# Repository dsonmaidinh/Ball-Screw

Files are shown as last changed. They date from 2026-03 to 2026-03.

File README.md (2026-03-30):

# Dự án BallScrew Control

Tài liệu trong thư mục này giới thiệu hệ thống điều khiển BallScrew gồm phần cứng, phần mềm và firmware.

## Nội dung chính

- `App.png`: giao diện điều khiển và đồ thị hiển thị dữ liệu thời gian thực.
- `BallScrew.gif`: mô phỏng hoặc demo hoạt động cơ khí/điều khiển trong hệ thống.

## Mục tiêu

Dự án hướng tới xây dựng một hệ thống điều khiển vị trí/velocity cho cơ cấu BallScrew:

- STM32 F4 làm bộ điều khiển chính.
- Điều khiển PID kết hợp với encoder để theo dõi vị trí.
- Giao tiếp UART với phần mềm PC để hiển thị đồ thị và gửi lệnh.

## Hình ảnh minh họa

### Giao diện ứng dụng

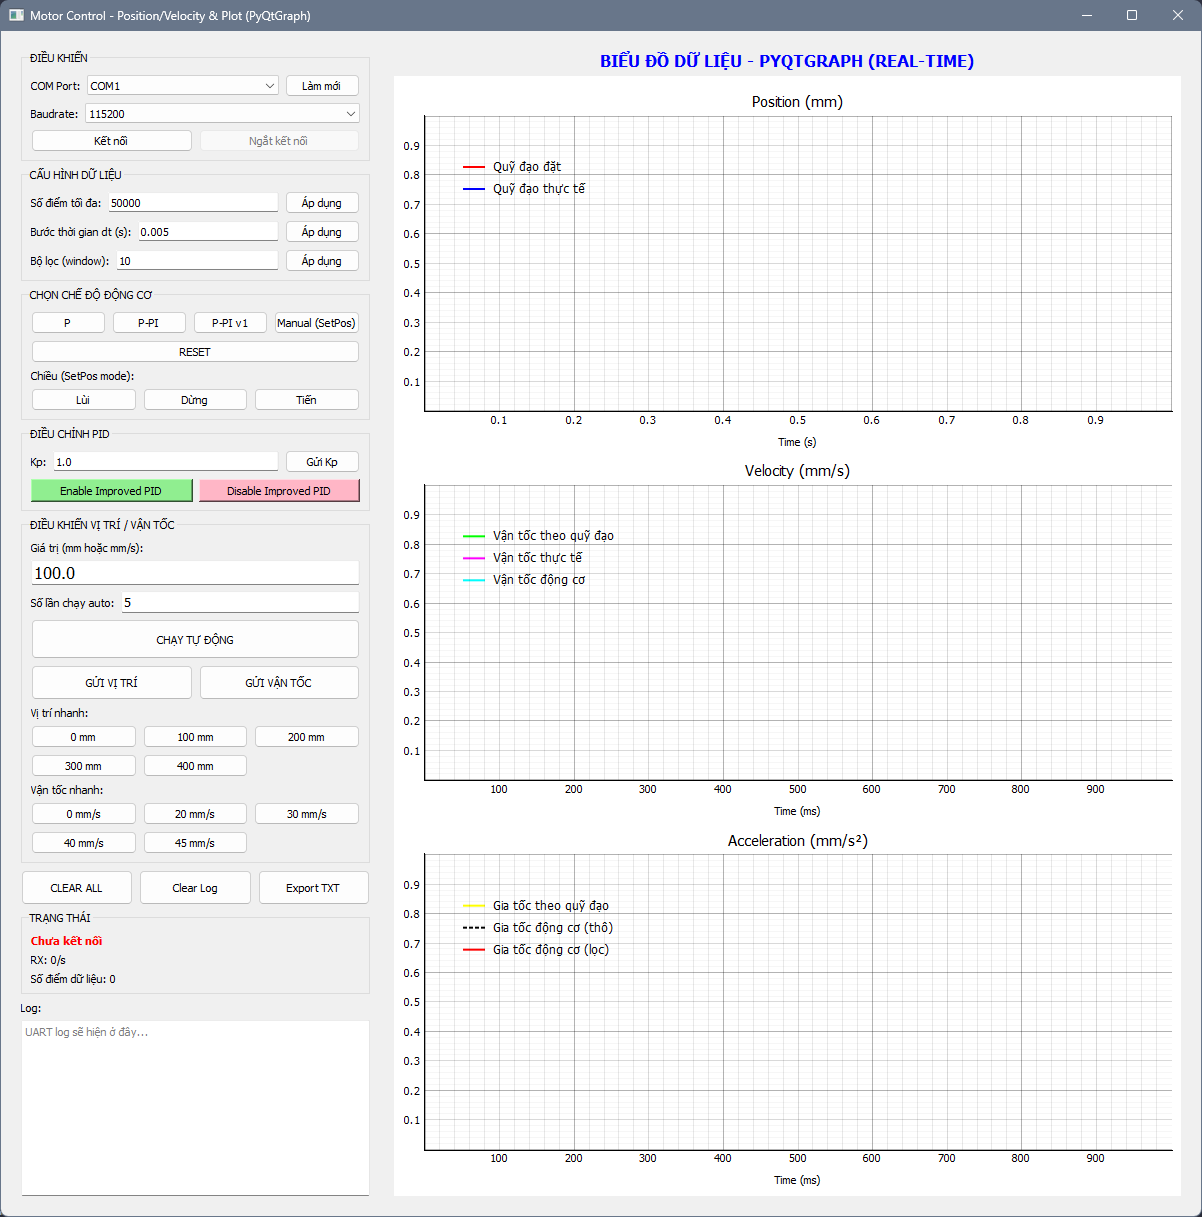
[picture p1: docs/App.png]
Giao diện ứng dụng điều khiển BallScrew


### Demo hoạt động

Demo hoạt động BallScrew

## Hướng dẫn nhanh

1. Mở firmware trong thư mục `firmware`.
2. Build và nạp vào STM32 F4.
3. Chạy ứng dụng PC trong `software/BallScrew.py`.
4. Kết nối cổng COM và bắt đầu điều khiển.

## Ghi chú

- Ảnh và GIF trong thư mục `docs` dùng để mô tả giao diện và trạng thái hệ thống.
- Tài liệu chính vẫn nằm trong README của từng phần `firmware`, `hardware`, `software`.

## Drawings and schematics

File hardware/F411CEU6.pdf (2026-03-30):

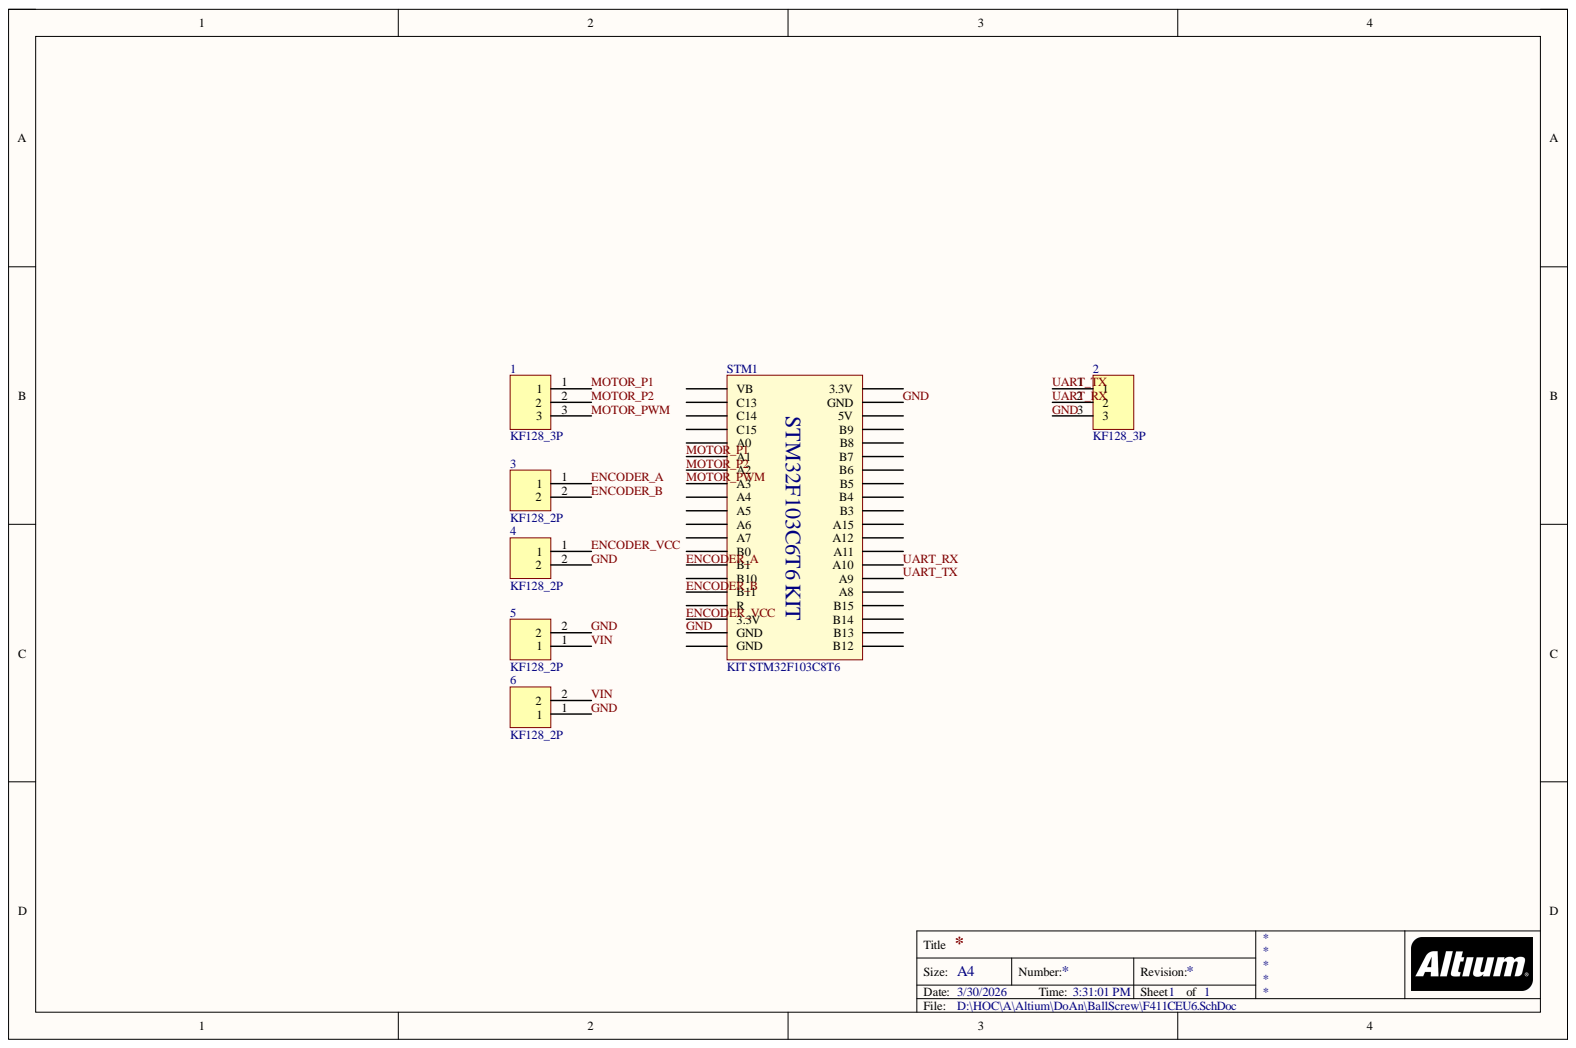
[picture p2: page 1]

Titl e * | **** *

Siz e : A4 | Numbe r : * | R evision : *

Da te : 3/30/202 6 Time : 3:31:01 P M | | She e t 1 o f 1

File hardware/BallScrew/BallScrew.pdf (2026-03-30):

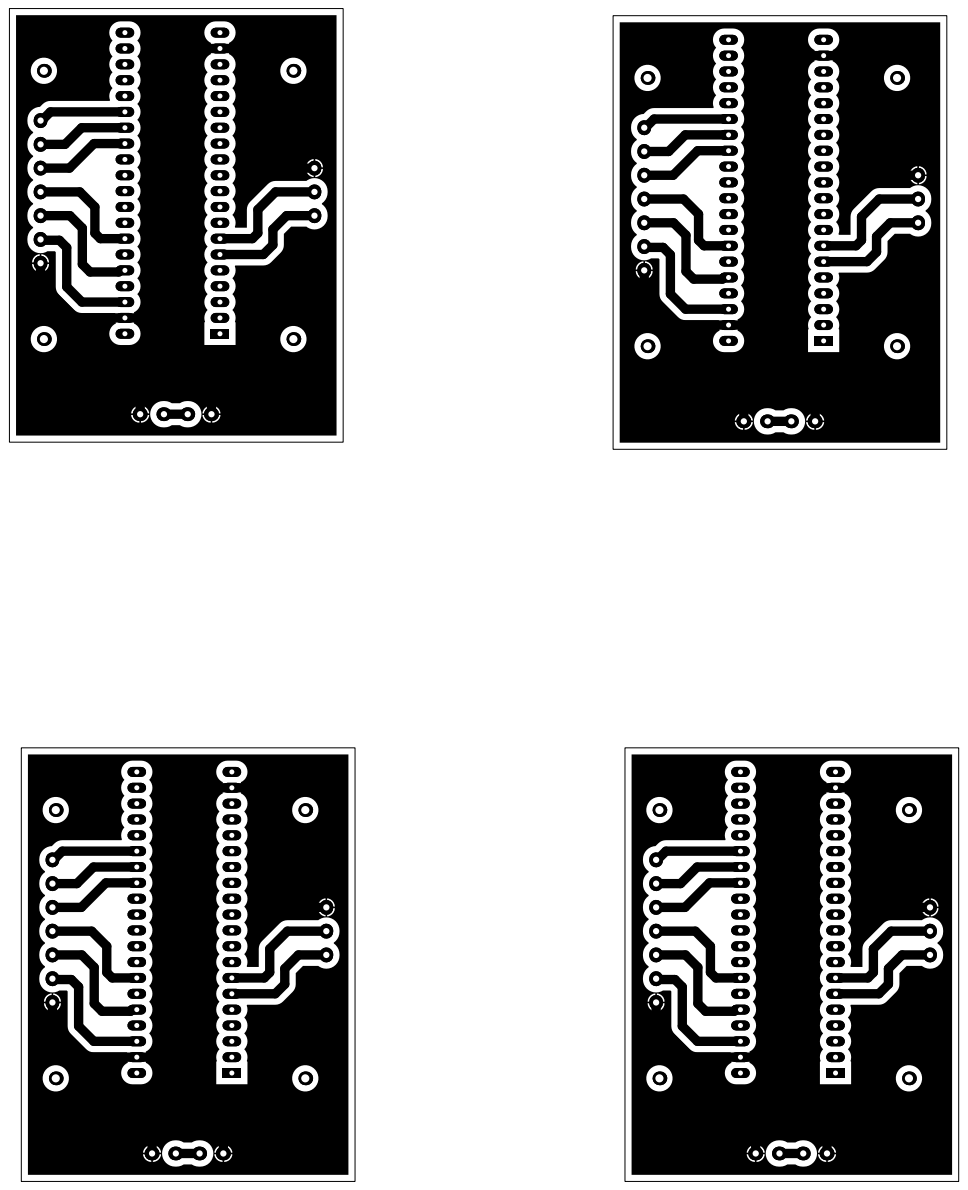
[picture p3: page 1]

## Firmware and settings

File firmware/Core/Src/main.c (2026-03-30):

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
/* Includes ------------------------------------------------------------------*/
#include "main.h"

/* USER CODE BEGIN Includes */
#include "stdio.h"
#include "string.h"
#include "stdlib.h"
#include "stdbool.h"
#include "math.h"

#include "encoder.h"
#include "motor.h"
#include "pid_controller.h"
#include "system_config.h"
#include "trajectory.h"
#include "uart.h"

/* USER CODE END Includes */

TIM_HandleTypeDef htim2;
TIM_HandleTypeDef htim4;

UART_HandleTypeDef huart1;
DMA_HandleTypeDef hdma_usart1_rx;
DMA_HandleTypeDef hdma_usart1_tx;

void SystemClock_Config(void);
static void MX_GPIO_Init(void);
static void MX_DMA_Init(void);
static void MX_TIM2_Init(void);
static void MX_USART1_UART_Init(void);
static void MX_TIM4_Init(void);
/* USER CODE BEGIN PFP */
//=== Vel: PI
#if 1
float Kp 	= 8.7719;
float Ki 	= 438.5965;
float Kb 	= 50.0000;
float Kd  = 0;
float alpha_vel = 0.0f;

//float Kp 	= 23.3;
//float Ki 	= 776.67;
//float Kb 	= 33.33;//;
//float Kd  = 0;
//float alpha_vel = 0.0f;
#endif
#if 0
float Kp 	= 1.1363;//0.2058;
float Ki 	= 37.8261;//6.3327;
float Kb 	= 33.2889;//;
float Kd  = 0;
float alpha_vel = 0.0f;
#endif
//=== Improved Profile Gains
float	Kp_pos = 800.0;
float Kpp_improved = 10.0;   // P gain position controller
//float Kpp_improved = 5.0;   // P gain position controller
float Kest = 100000.0;           // Estimation gain (< 1.0: overdamped, > 1.0: underdamped)
float Kcom = 20.0;           	 // Compensation gain (< 1.0: overdamped, > 1.0: underdamped)
//=== Uart
char Rx_indx, Rx_Buffer[MaxBuffer],Rx_data[MaxBuffer];
//char Tx_Buffer[MaxBuffer];
volatile uint8_t uart1_flag = 0;

encoder Encoder = {0};
motor Motor = {0};
pid_controller PIDVel;
pid_controller PIDPos;
Trajectory_t trajectory = {0};
/* USER CODE END PFP */

/* USER CODE BEGIN 0 */
float max_pwm_P = SYS_MaxPWM_P;
float speed = 0;
int8_t chieu = 0;
uint32_t count_element = 0;
char Tx_Buffer[MaxBuffer];  // 2 buffer xen kẽ
volatile uint8_t active_buffer = 0;
volatile uint8_t dma_busy = 0;
PlotBuffer_t plot_buffer = {0};

void HAL_TIM_PeriodElapsedCallback(TIM_HandleTypeDef *htim) {
    if(htim->Instance == TIM4) {    // 5ms
			switch(Motor.mode){
				case MOTOR_SetPos:
					MOTOR_CalculateParams(&Motor, &Encoder, trajectory.sign, trajectory.phase);
					speed = Motor.CurVel_rad;
					if(chieu == -1) Motor.pwm = -1000;
					else if(chieu == 0) Motor.pwm = 0;
					else Motor.pwm = 1000;					break;
				
				case MOTOR_P_PI:
					// TÍNH TOÁN THÔNG SỐ
					MOTOR_CalculateParams(&Motor, &Encoder, trajectory.sign, trajectory.phase);
					// CẬP NHẬT TRAJECTORY
					if(trajectory.use_v1) TRAJ_DrawTrajectory_v1(&trajectory);
					else TRAJ_DrawTrajectory(&trajectory);
					// PID VỊ TRÍ
					Motor.DesiredVel_mm = PID_Pos_Improved(&PIDPos, trajectory.q_desired, Motor.CurPos_mm);
					Motor.DesiredVel_rad = Motor.DesiredVel_mm * SYS_MM2RAD;
					//if(fabs(Motor.DesiredVel_rad) < 0.85) Motor.DesiredVel_rad = 0;
					// PID VẬN TỐC
					Motor.pwm = PID_Vel(&PIDVel, Motor.DesiredVel_rad, Motor.CurVel_rad, trajectory.phase, trajectory.sign);
					break;
				case MOTOR_P:
					// TÍNH TOÁN THÔNG SỐ
					MOTOR_CalculateParams(&Motor, &Encoder, trajectory.sign, trajectory.phase);
					// CẬP NHẬT TRAJECTORY
					if(trajectory.use_v1) TRAJ_DrawTrajectory_v1(&trajectory);
					else TRAJ_DrawTrajectory(&trajectory);
					// PID VỊ TRÍ
					Motor.pwm = PID_Pos_Simple(&PIDPos, trajectory.q_desired, Motor.CurPos_mm);
					

					break;
			}
			if(Motor.tick_enabled) Motor.tick++;
			MOTOR_SetRun(&Motor);
			#if 1
			if (Motor.plot_active) {
            // Ghi d? li?u vào buffer
            if (plot_buffer.count < PLOT_BUFFER_SIZE) {
                PlotData_t *data = &plot_buffer.buffer[plot_buffer.write_idx];
                
                data->q_desired = trajectory.q_desired_prev;
                data->q_actual = Motor.CurPos_mm;
                data->v_desired = 0.0;
                data->v_actual = (float)Motor.DesiredVel_mm;
                data->v_motor = Motor.CurVel_mm;
                data->a_desired = 0.0;
                data->a_motor = Motor.Acc_mm;
								data->pwm = Motor.pwm;
								
                plot_buffer.write_idx = (plot_buffer.write_idx + 1) % PLOT_BUFFER_SIZE;
                
                // CRITICAL: Tang count ph?i atomic
                __disable_irq();
                plot_buffer.count++;
                __enable_irq();
            }
        }
			// Cập nhật state
			trajectory.v_desired_prev = trajectory.v_desired;
			trajectory.q_desired_prev = trajectory.q_desired;
			#endif
    }
}
void HAL_UART_TxCpltCallback(UART_HandleTypeDef *huart) {
    if(huart->Instance == USART1) {
        dma_busy = 0;  // Cho phép gửi tiếp
    }
}  
/* USER CODE END 0 */

/**
  * @brief  The application entry point.
  * @retval int
  */
int main(void)
{

  /* MCU Configuration--------------------------------------------------------*/

  /* Reset of all peripherals, Initializes the Flash interface and the Systick. */
  HAL_Init();

  /* Configure the system clock */
  SystemClock_Config();

  /* Initialize all configured peripherals */
  MX_GPIO_Init();
  MX_DMA_Init();
  MX_TIM2_Init();
  MX_USART1_UART_Init();
  MX_TIM4_Init();
  /* Infinite loop */
  /* USER CODE BEGIN WHILE */
	//--- Timer
	HAL_TIM_Base_Start_IT(&htim4);
	//--- PWM
	HAL_TIM_PWM_Start(&htim2, TIM_CHANNEL_3);
	//--- UART
	UART_Receive_Enable(&huart1, (uint8_t *)Rx_Buffer, MaxBuffer);
	//--- SetParams
	
	MOTOR_SetParams(&Motor, TIM_CHANNEL_3, MOTOR_PIN_1, MOTOR_PIN_2, MOTOR_SetPos, MOTOR_MAXVEL_MM);
	PID_SetParams(&PIDVel, Kp, Ki, Kd, Kb, alpha_vel, SYS_MaxPWM, SYS_SAMPLETIME);
	if(Motor.mode == MOTOR_P)PID_SetParamsImproved(&PIDPos, Kp_pos, SYS_MaxPWM_P, SYS_SAMPLETIME, Kest, Kcom, Motor.a_max_mm);
	else PID_SetParamsImproved(&PIDPos, Kpp_improved, Motor.v_max_mm, SYS_SAMPLETIME, Kest, Kcom, Motor.a_max_mm);
	PID_ResetState(&PIDPos);

	TRAJ_SetParams(&trajectory, SYS_SAMPLETIME, SYS_RUN_TIME, SYS_STOP_TIME, Motor.a_max_mm * 2.0, Motor.v_max_mm);
	
	float Kpp_improved_pre = Kpp_improved;
	float preKest = Kest;
	float preKcom = Kcom;
	float premax_pwm_P = max_pwm_P;
	float preKp_pos = Kp_pos;
//	trajectory.test = 1;
//	Motor.pwm = 1000;
//	trajectory.sign = 1;
//	HAL_Delay(1000);
//	MOTOR_SetRun(&Motor);
//	__HAL_TIM_SetCompare(&htim2, TIM_CHANNEL_3, 1000);
  while (1)
  {
			#if 1
			if(plot_buffer.reset) {
					chieu = 0;
					memset(Tx_Buffer, 0, sizeof(Tx_Buffer));
					UART_ResetPlotData(&plot_buffer);
				
					MOTOR_ResetParams(&Motor);
					ENCODER_ResetParams(&Encoder);
					TRAJ_ResetParams(&trajectory);
					PID_ResetParams(&PIDVel);
					plot_buffer.reset = 0;
					HAL_Delay(200);
			}
			switch(Motor.mode){
					case MOTOR_SetPos:
						break;
					
					case MOTOR_P_PI:
							if (plot_buffer.count > 0 && !dma_busy) {
									PlotData_t *data = &plot_buffer.buffer[plot_buffer.read_idx];
									
									int len = snprintf(Tx_Buffer, MaxBuffer,
																		"%.3f %.3f %.3f %.3f %.3f %.3f %.3f %.3f 0.0\r\n",
																		data->q_desired,
																		data->q_actual,
																		data->v_desired,
																		data->v_actual,
																		data->v_motor,
																		data->a_desired,
																		data->a_motor,
																		data->pwm
																		);
									
									if (len > 0 && len < MaxBuffer) {
											dma_busy = 1;
											HAL_UART_Transmit_DMA(&huart1, (uint8_t *)Tx_Buffer, len);
											
											plot_buffer.read_idx = (plot_buffer.read_idx + 1) % PLOT_BUFFER_SIZE;
											
											__disable_irq();
											plot_buffer.count--;
											__enable_irq();
											
											count_element++;
									}
							}
						if(trajectory.phase == TRAJ_PHASE_STOP) {  // Đã gần đích
								Motor.tick_enabled = 1;
								
								if(Motor.tick >= 400){  // 400 * 5ms = 2s
										// Sau 2s mà vẫn sai số > 10mm => CÓ LỖI
										if(fabs(trajectory.q_desired - Motor.CurPos_mm) > 10.0) {
												plot_buffer.reset = 1;
												PIDVel.err_state = 1;
										}
										else {
												// Đã ổn định => tắt tick
												Motor.check = 0;
												Motor.tick_enabled = 0;
										}
										Motor.tick = 0;
								}
						}
						else {
								// Động cơ đang chuyển động hoặc chưa gần đích => KHÔNG kiểm tra lỗi
								Motor.tick_enabled = 0;
								Motor.tick = 0;
						}
						break;
					case MOTOR_P:
							if (plot_buffer.count > 0 && !dma_busy) {
								PlotData_t *data = &plot_buffer.buffer[plot_buffer.read_idx];
								
								int len = snprintf(Tx_Buffer, MaxBuffer,
																	"%.3f %.3f %.3f %.3f %.3f %.3f %.3f %.3f 0.0\r\n",
																	data->q_desired,
																	data->q_actual,
																	0.0,
																	0.0,
																	data->v_motor,
																	0.0,
																	data->a_motor,
																	data->pwm
																	);
								
								if (len > 0 && len < MaxBuffer) {
										dma_busy = 1;
										HAL_UART_Transmit_DMA(&huart1, (uint8_t *)Tx_Buffer, len);
										
										plot_buffer.read_idx = (plot_buffer.read_idx + 1) % PLOT_BUFFER_SIZE;
										
										__disable_irq();
										plot_buffer.count--;
										__enable_irq();
										
										chieu += 1.0;
								}
						}
						break;
				}
				if(Motor.DesiredPos_mm != Motor.DesiredPos_mm_pre){
						trajectory.plot_active = 1;
						trajectory.move_active = 1;
						Motor.plot_active = 1;
						Motor.tick_enabled = 0;
						Motor.tick = 0;
						Motor.DesiredPos_mm_pre = Motor.DesiredPos_mm;
								TRAJ_SetupMultiSegmentMove_100mm(&trajectory, Motor.DesiredPos_mm);
								TRAJ_ContinueNextSegment_100mm(&trajectory);
						PID_ResetState(&PIDPos);
				}
				if(trajectory.phase == TRAJ_PHASE_COMPLETE && 
					 (fabs(Motor.DesiredPos_mm - Motor.CurPos_mm)) <= Motor.cycle_error[Motor.cycle_index] && 
					 Motor.auto_run)
				{
						if(Motor.cycle_count > 0){
								// Kiểm tra đang ở vị trí nào
								if(fabs(Motor.DesiredPos_mm_pre) < 0.1){
										// Đang ở vị trí 0 → Đi đến vị trí đích
										Motor.DesiredPos_mm = Motor.AutoDesiredPos_mm;
								} else {
										// Đang ở vị trí đích → Quay về 0
										Motor.DesiredPos_mm = 0;
										
										// Giảm cycle sau khi hoàn thành 1 chu kỳ đầy đủ (đi + về)
										Motor.cycle_count--;
								}
						}
						else {
								// Hết cycle → Dừng auto_run
								Motor.auto_run = 0;
								Motor.DesiredPos_mm_pre = 0;
						}
				}
				#endif
				HAL_Delay(1);
    /* USER CODE END WHILE */

    /* USER CODE BEGIN 3 */
  }
  /* USER CODE END 3 */
}

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
/* USER CODE BEGIN 4 */
struct __FILE
{
  int handle;
  
};
/* FILE is typedef'd in stdio.h. */
FILE __stdout;
int fputc(int ch, FILE *f)
{
  /* Your implementation of fputc(). */
	HAL_UART_Transmit(&huart1, (uint8_t *) &ch,1,100);
//	HAL_UART_Transmit_DMA(&huart1, (uint8_t *) &ch,1);

  return ch;
}
// Ham ngat Uart
void HAL_UARTEx_RxEventCallback(UART_HandleTypeDef *huart, uint16_t Size){
    if (huart->Instance == USART1)
    {
        UART_Receive_Enable(&huart1, (uint8_t *)Rx_Buffer, MaxBuffer);
        
				char first_char = Rx_Buffer[0];
				if(first_char == 'r'){
						plot_buffer.reset = 1;
						PIDVel.err_state = 0;
						return;
				}
				memcpy(Rx_data, Rx_Buffer, MaxBuffer * sizeof(Rx_Buffer[0]));
				switch(first_char){
					case 'm':
								MOTOR_ResetParams(&Motor);
								ENCODER_ResetParams(&Encoder);
								TRAJ_ResetParams(&trajectory);
								if(strcmp(Rx_Buffer, "mode 0") == 0){
										Motor.cycle_index = 1;
										MOTOR_UpdateMode(&Motor, MOTOR_P);
										PID_SetParamsImproved(&PIDPos, Kp_pos, SYS_MaxPWM_P, SYS_SAMPLETIME, Kest, Kcom, Motor.a_max_mm);
								}
								else if(strcmp(Rx_Buffer, "mode 1") == 0){
										Kpp_improved = 5.0;
										trajectory.use_v1 = 0;
										Motor.cycle_index = 0;
										MOTOR_UpdateMode(&Motor, MOTOR_P_PI);
										PID_SetParamsImproved(&PIDPos, Kpp_improved, Motor.v_max_mm, SYS_SAMPLETIME, Kest, Kcom, Motor.a_max_mm);
								}
								else if(strcmp(Rx_Buffer, "mode 2") == 0){
										trajectory.use_v1 = 1;
										Motor.cycle_index = 0;
										MOTOR_UpdateMode(&Motor, MOTOR_P_PI);
										PID_SetParamsImproved(&PIDPos, Kpp_improved, Motor.v_max_mm, SYS_SAMPLETIME, Kest, Kcom, Motor.a_max_mm);
								}
								else{
										MOTOR_UpdateMode(&Motor, MOTOR_SetPos);
										trajectory.sign = 1;
								}
								plot_buffer.reset = 1;
								break;
					case 'c':
								if(Motor.mode == MOTOR_SetPos){
										if(strcmp(Rx_Buffer, "c-1") == 0){
												chieu = -1;
										}
										else if(strcmp(Rx_Buffer, "c0") == 0){
												chieu = 0;
										}
										else{
												chieu = 1;
										}
								}
					case 'x':
										{
											char *token1 = strtok(Rx_Buffer + 1, "x");  // Bỏ ký tự 'x' đầu
											char *token2 = strtok(NULL, "x");
											
											if (token1 != NULL && token2 != NULL) {
													int position = atof(token1);
													int cycles = atoi(token2);
													
													// Lưu vào struct trajectory hoặc motor
													MOTOR_UpdatePos(&Motor, position);
													Motor.AutoDesiredPos_mm = Motor.DesiredPos_mm;
													Motor.cycle_count = cycles;
													Motor.auto_run = 1;  // Bật chế độ chu trình
											}
										}
										break;
					default:
								break;
				}
				
				if(Motor.mode != MOTOR_SetPos){
						// Lấy ký tự cuối cùng làm command
						char last_char = Rx_Buffer[Size - 1];
						
						switch(last_char) {
								case 's':
										// Thay ký tự 's' bằng null terminator để atoi chỉ đọc phần số
										Rx_Buffer[Size - 1] = '\0';
										MOTOR_UpdatePos(&Motor, atoi(Rx_Buffer));
										break;
										
								case 'v':
										if(Motor.mode == MOTOR_P) break;
										// Thay ký tự 'v' bằng null terminator để atoi chỉ đọc phần số
										Rx_Buffer[Size - 1] = '\0';
										MOTOR_UpdateVel(&Motor, atoi(Rx_Buffer));
										
										PID_SetParamsImproved(&PIDPos, Kpp_improved, Motor.v_max_mm, SYS_SAMPLETIME, Kest, Kcom, Motor.a_max_mm);
										TRAJ_SetParams(&trajectory, SYS_SAMPLETIME, SYS_RUN_TIME, SYS_STOP_TIME, Motor.a_max_mm, Motor.v_max_mm);
										break;    
										
								case 'p':
										Rx_Buffer[Size - 1] = '\0';
										if(Motor.mode == MOTOR_P){
												Kp_pos = atof(Rx_Buffer);
												PID_SetParamsImproved(&PIDPos, Kp_pos, SYS_MaxPWM_P, SYS_SAMPLETIME, Kest, Kcom, Motor.a_max_mm);
										}
										else{
												Kpp_improved = atof(Rx_Buffer);
												PID_SetParamsImproved(&PIDPos, Kpp_improved, Motor.v_max_mm, SYS_SAMPLETIME, Kest, Kcom, Motor.a_max_mm);
										}
								case 'e':
										if(Motor.mode == MOTOR_P) break;
										Rx_Buffer[Size - 1] = '\0';
										if(atoi(Rx_Buffer) == 0)	PID_DisableImproved(&PIDPos);
										else PID_EnableImproved(&PIDPos);
										break;

								default:
										break;
						}
				}
        
        // Reset buffer
        memset(Rx_Buffer, 0, sizeof(Rx_Buffer));
    }
}

void HAL_GPIO_EXTI_Callback(uint16_t GPIO_Pin){
    if(GPIO_Pin == Encoder_A || GPIO_Pin == Encoder_B) {
        ProcessEncoder(&Encoder, Encoder_A, Encoder_B);
    }
}
/* USER CODE END 4 */
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


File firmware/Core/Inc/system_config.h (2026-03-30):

#ifndef SYSTEM_CONFIG_H
#define SYSTEM_CONFIG_H

#include <stdint.h>
//#include "motor.h"

// TOÁN HỌC
#define SYS_PI 							3.1415
#define SYS_RAD2MM					2.0/SYS_PI
#define SYS_MM2RAD					SYS_PI/2.0
// HỆ VÍT ME
#define SYS_PB							4.0
#define SYS_MAXLENGTH				400.0
#define SYS_MINLENGTH				0.0
// ĐỘNG CƠ
#define MOTOR_PORT 			GPIOA
#define MOTOR_PIN_1			0
#define MOTOR_PIN_2			1
#define SYS_SAMPLETIME			0.005
// ENCODER
#define Encoder_Port		GPIOB
#define Encoder_A				GPIO_PIN_0
#define Encoder_B				GPIO_PIN_2
#define Encoder_ppr 		8000

#define SYS_MaxPWM				  1000
#define SYS_MaxPWM_P			  800
// THỜI GIAN
#define SYS_RUN_TIME				2.1
#define SYS_STOP_TIME				12.9
#endif

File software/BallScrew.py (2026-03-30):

import sys
import threading
import time
from collections import deque

from PyQt5 import QtCore, QtGui, QtWidgets
import serial
import serial.tools.list_ports

import pyqtgraph as pg
from pyqtgraph import PlotWidget, PlotItem


# ---------------------------
# PyQtGraph Canvas Widget
# ---------------------------
class PyQtGraphCanvas(pg.GraphicsLayoutWidget):
    def __init__(self, parent=None):
        super().__init__(parent)
        
        # Set background
        self.setBackground('w')
        
        # Create subplots
        self.pos_plot = self.addPlot(title="Position (mm)", row=0, col=0)
        self.nextRow()
        self.vel_plot = self.addPlot(title="Velocity (mm/s)", row=1, col=0)
        self.nextRow()
        self.acc_plot = self.addPlot(title="Acceleration (mm/s²)", row=2, col=0)
        
        # Link X axes
        self.vel_plot.setXLink(self.pos_plot)
        self.acc_plot.setXLink(self.pos_plot)
        
        # Configure plots
        for plot in [self.pos_plot, self.vel_plot, self.acc_plot]:
            plot.showGrid(x=True, y=True, alpha=0.3)
            plot.addLegend()
        
        # Data curves
        self.curves = {}
        self._setup_curves()
    
    def _setup_curves(self):
        # Position curves
        self.curves['dpos'] = self.pos_plot.plot(pen=pg.mkPen('r', width=2), name="Quỹ đạo đặt")
        self.curves['cpos'] = self.pos_plot.plot(pen=pg.mkPen('b', width=2), name="Quỹ đạo thực tế")
        
        # Velocity curves  
        self.curves['vdes'] = self.vel_plot.plot(pen=pg.mkPen('g', width=2), name="Vận tốc theo quỹ đạo")
        self.curves['vactual'] = self.vel_plot.plot(pen=pg.mkPen('m', width=2), name="Vận tốc thực tế")
        self.curves['vmotor'] = self.vel_plot.plot(pen=pg.mkPen('c', width=2), name="Vận tốc động cơ")
        
        # Acceleration curves
        self.curves['ades'] = self.acc_plot.plot(pen=pg.mkPen('y', width=2), name="Gia tốc theo quỹ đạo")
        self.curves['amotor'] = self.acc_plot.plot(pen=pg.mkPen('k', width=2, style=QtCore.Qt.DotLine), name="Gia tốc động cơ (thô)")
        self.curves['amotor_filtered'] = self.acc_plot.plot(pen=pg.mkPen('r', width=2), name="Gia tốc động cơ (lọc)")
        
        # Set X-axis label to time
        self.pos_plot.setLabel('bottom', 'Time', units='s')
        self.vel_plot.setLabel('bottom', 'Time', units='s')
        self.acc_plot.setLabel('bottom', 'Time', units='s')
    
    def update_plot(self, x, pos_data, vel_data, acc_data):
        # Update all curves with new data
        self.curves['dpos'].setData(x, pos_data[0])
        self.curves['cpos'].setData(x, pos_data[1])
        
        self.curves['vdes'].setData(x, vel_data[0])
        self.curves['vactual'].setData(x, vel_data[1])
        self.curves['vmotor'].setData(x, vel_data[2])
        
        self.curves['ades'].setData(x, acc_data[0])
        self.curves['amotor'].setData(x, acc_data[1])
        self.curves['amotor_filtered'].setData(x, acc_data[2])
    
    def clear_plot(self):
        # Clear all curve data
        for curve in self.curves.values():
            curve.clear()
        
        # Reset plot ranges
        for plot in [self.pos_plot, self.vel_plot, self.acc_plot]:
            plot.enableAutoRange()


# ---------------------------
# Serial Reader Thread
# ---------------------------
class SerialReader(QtCore.QObject):
    line_received = QtCore.pyqtSignal(str)
    connected = QtCore.pyqtSignal(bool)

    def __init__(self):
        super().__init__()
        self.ser = None
        self._running = False
        self._thread = None

    def list_ports(self):
        return [p.device for p in serial.tools.list_ports.comports()]

    def open(self, port, baud):
        try:
            self.ser = serial.Serial(port=port, baudrate=baud, timeout=0.01)
            self._running = True
            self._thread = threading.Thread(target=self._reader_loop, daemon=True)
            self._thread.start()
            self.connected.emit(True)
            return True
        except Exception as e:
            self.connected.emit(False)
            QtWidgets.QMessageBox.critical(None, "Serial Error", str(e))
            return False

    def _reader_loop(self):
        buf = bytearray()
        while self._running and self.ser is not None:
            try:
                data = self.ser.read(512)
                if data:
                    buf.extend(data)
                    while b'\n' in buf:
                        line, _, buf = buf.partition(b'\n')
                        try:
                            s = line.decode('utf-8', errors='ignore').strip()
                            if s:
                                self.line_received.emit(s)
                        except Exception:
                            pass
                else:
                    time.sleep(0.001)
            except Exception:
                break
        self.connected.emit(False)

    def write_text(self, text: str):
        if self.ser and self.ser.is_open:
            try:
                self.ser.write(text.encode('utf-8'))
            except Exception as e:
                QtWidgets.QMessageBox.warning(None, "Write Error", str(e))

    def close(self):
        self._running = False
        try:
            if self.ser:
                self.ser.close()
        except Exception:
            pass
        self.ser = None
        self.connected.emit(False)
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

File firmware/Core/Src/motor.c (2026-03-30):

#include "motor.h"
#include "stm32f4xx.h"
#include "system_config.h"
#include <stdbool.h>
#include <math.h>

extern TIM_HandleTypeDef htim2;

void MOTOR_SetRun(motor *Motor){
		int8_t next_dir = 0;
    
    // 1. Xác định hướng TƯƠNG LAI dựa trên PWM
    if(Motor->pwm >= 0) {
        next_dir = 1; // Ví dụ: -1 là chiều thuận
    } else {
        next_dir = -1;  // Ví dụ: 1 là chiều nghịch
    }

    // 2. So sánh hướng tương lai và hướng hiện tại
    if(next_dir != Motor->dir){
        // Nếu đảo chiều, Reset cả 2 chân trước để tránh xung đột
        MOTOR_PORT->ODR &= ~((1<<Motor->mpin[0]) | (1<<Motor->mpin[1]));
        Motor->dir = next_dir; // Cập nhật hướng mới
    }
    
    // 3. Thực hiện điều khiển
    Motor->pwm_real = (Motor->pwm >= 0) ? Motor->pwm : -Motor->pwm;
    static int8_t pre_dir = 0;
    if(Motor->pwm >= 0) {
        MOTOR_PORT->ODR |= 1<<Motor->mpin[0];
    }
    else if(Motor->pwm < 0) {
        MOTOR_PORT->ODR |= 1<<Motor->mpin[1];
    }
    __HAL_TIM_SetCompare(&htim2, Motor->pwmchannel, Motor->pwm_real);
}

void MOTOR_SetParams(motor *Motor, uint32_t ch, uint8_t pin1, uint8_t pin2, MotorMode mode, float max_speed_mm){
    Motor->pwmchannel = ch;
    Motor->mpin[0]    = pin1;
    Motor->mpin[1]    = pin2;
    
		Motor->cycle_error[0] = 0.1;
		Motor->cycle_error[1] = 0.9;
	
    Motor->state      = MOTOR_IDLE;
    Motor->prev_state = MOTOR_IDLE;
	
		Motor->v_max_mm	  =	max_speed_mm;
		Motor->a_max_mm	  = (max_speed_mm/MOTOR_RESPONSETIME)*MOTOR_MAXACC_SF;
		MOTOR_UpdateMode(Motor, mode);
}

void MOTOR_ResetParams(motor *Motor){
		Motor->DesiredPos_mm = 0;
		Motor->DesiredPos_mm_pre = 0;
		Motor->CurPos_mm = 0;
	
		Motor->DesiredVel_mm = 0;
		Motor->DesiredVel_rad = 0;
	
		Motor->plot_active = 0;
		Motor->auto_run = 0;
		Motor->cycle_count = 0;
		//Motor->cycle_index = 0;
		Motor->tick = 0;
		Motor->tick_enabled = 0;
		Motor->check = 0;
		MOTOR_PORT->ODR &= ~((1<<Motor->mpin[0]) | (1<<Motor->mpin[1]));
}

void MOTOR_UpdateMode(motor *Motor, MotorMode mode){
		Motor->mode       = mode;
		if(mode == MOTOR_P) Motor->err_pos = 0.5;
		else Motor->err_pos = 0.01;
}
void MOTOR_UpdateVel(motor *Motor, float vel){
		Motor->v_max_mm	  =	vel;
		if (Motor->v_max_mm >= MOTOR_MAXVEL_MM) Motor->v_max_mm = MOTOR_MAXVEL_MM;
    if (Motor->v_max_mm <= MOTOR_MINVEL_MM) Motor->v_max_mm = MOTOR_MINVEL_MM;
		Motor->a_max_mm	  = (Motor->v_max_mm/MOTOR_RESPONSETIME)*MOTOR_MAXACC_SF;
}
void MOTOR_UpdatePos(motor *Motor, float pos){
		Motor->DesiredPos_mm	  =	pos;
		if (Motor->DesiredPos_mm >= SYS_MAXLENGTH) Motor->DesiredPos_mm = SYS_MAXLENGTH;
    if (Motor->DesiredPos_mm <= SYS_MINLENGTH) Motor->DesiredPos_mm = SYS_MINLENGTH;
}

void MOTOR_CalculateParams(motor *Motor, encoder *Encoder, float sign, MotionPhase_t phase){
    Encoder->Cnttmp 	= Encoder->CntVel;
    Encoder->CntVel 	= 0;
    Motor->CurVel_rad = sign * Encoder->Cnttmp * MOTOR_VEL_CONVERSION_FACTOR_RAD;
    Motor->CurPos_mm 	= ((float)Encoder->PosCnt + (float)Encoder->CountValue / (float)Encoder_ppr) * SYS_PB;
    
    // Chuyển đổi vận tốc sang mm/s để so sánh
    if(Motor->mode == MOTOR_P) Motor->CurVel_mm = Motor->CurVel_rad;
    else Motor->CurVel_mm = Motor->CurVel_rad * SYS_RAD2MM;
    
    // Lọc nhiễu: nếu vận tốc thực tế < ngưỡng nhiễu thì coi như 0
    if(fabs(Motor->CurVel_mm) < MOTOR_DEADZONE_VEL) {
        Motor->CurVel_mm = 0.0f;
    }
//else Motor->state = MOTOR_ACCEL;
    
    Motor->vel_diff = Motor->CurVel_mm - Motor->CurVel_mm_pre;

    //MOTOR_CalculateTime_v1(Motor, time, phase);
    if(fabs(Motor->DesiredPos_mm - Motor->CurPos_mm) < Motor->err_pos && phase == TRAJ_PHASE_COMPLETE){
        Motor->plot_active = 0;
    }
		
    Motor->CurVel_mm_pre = Motor->CurVel_mm;
    
    // Tính gia tốc thực tế
    Motor->Acc_mm = 0.8f * Motor->Acc_mm + 0.2f * ((Motor->vel_diff) / SYS_SAMPLETIME);
}

// void MOTOR_CalculateTime(motor *Motor) {
//     static float t_stable_count = 0.0f;    // Thời gian ổn định
//     static float prev_pos = 0.0f;          // Vị trí trước để để kiểm tra
//     static bool is_stabilizing = false;    // Đang trong quá trình ổn định
    
//     float error_at_max_speed = fabs(Motor->v_max_mm - Motor->CurVel_mm);
    
//     // ========== GIAI ĐOẠN ỔN ĐỊNH (sau khi giảm tốc) ==========
//     // Phát hiện bắt đầu ổn định: DesiredSpeed về 0 Và CurVel gần 0
//     if(fabs(Motor->DesiredVel_mm) < MOTOR_ACCEL_START_THRESHOLD && 
//        fabs(Motor->CurVel_mm) < MOTOR_DEADZONE_VEL && 
//        Motor->state == MOTOR_DECEL && 
//        !is_stabilizing) {
//         is_stabilizing = true;
//         t_stable_count = 0.0f;
//         prev_pos = Motor->CurPos_mm;
//         Motor->state = MOTOR_IDLE;
//     }
//     if(fabs(Motor->DesiredPos_mm - Motor->CurPos_mm) < 0.01f){
//         is_stabilizing = false;
//         t_stable_count = 0.0f;
//         Motor->t_motor_adjust = 0.0f;
//         Motor->state = MOTOR_IDLE;
//         Motor->plot_active = 0;
//     }
//     // Đang trong giai đoạn ổn định
//     if(is_stabilizing) {
//         float pos_change = fabs(Motor->CurPos_mm - prev_pos);
        
//         // Nếu vị trí thay đổi -> reset bộ đếm (động cơ vẫn đang điều chỉnh)
//         if(pos_change > 0.001f)  {
//             t_stable_count = 0.0f;
//             prev_pos = Motor->CurPos_mm;
//             Motor->t_motor_adjust += SYS_SAMPLETIME;  // Tích lũy thời gian tự điều chỉnh
//         }
//         else {
//             // Vị trí không đổi -> tăng bộ đếm
//             t_stable_count += SYS_SAMPLETIME;
//         }
        
//         // Nếu đã ổn định đủ lâu
//         if(t_stable_count >= MOTOR_STABILIZE_TIME) {
//             is_stabilizing = false;
//             t_stable_count = 0.0f;
//             Motor->t_motor_adjust = 0.0f;
//             Motor->state = MOTOR_IDLE;
//             Motor->plot_active = 0;
//         }
        
//         // Trong lúc ổn định, không cho phép chuyển state
//         Motor->prev_state = Motor->state;
//         Motor->CurVel_mm_pre = Motor->CurVel_mm;
//         return;
//     }
    
//     // ========== LOGIC CHUYỂN TRẠNG THÁI CHÍNH ==========
//     // --- IDLE -> ACCEL: Bắt đầu tăng tốc ---
//     // Dựa vào DesiredSpeed (và CurVel có deadzone)
//     if(Motor->state == MOTOR_IDLE && 
//        fabs(Motor->DesiredVel_mm) > MOTOR_ACCEL_START_THRESHOLD && 
// 			 fabs(Motor->CurVel_mm) > MOTOR_DEADZONE_VEL &&
//        !is_stabilizing) {
//         Motor->state = MOTOR_ACCEL;
//     }
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

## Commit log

2026-03-30 Initial commit: Hoàn thành dự án
    [DoAn_BallScrew.PrjPcb, F411CEU6.PcbDoc, F411CEU6.SchDoc]
2026-03-30 Hoàn thành dự án

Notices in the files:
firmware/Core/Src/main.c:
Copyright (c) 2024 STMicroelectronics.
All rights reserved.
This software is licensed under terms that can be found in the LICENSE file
